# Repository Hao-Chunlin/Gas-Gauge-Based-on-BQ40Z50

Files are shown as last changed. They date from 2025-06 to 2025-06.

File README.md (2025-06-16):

# 基于BQ40Z50电池电量计(Gas Gauge Based on BQ40Z50)
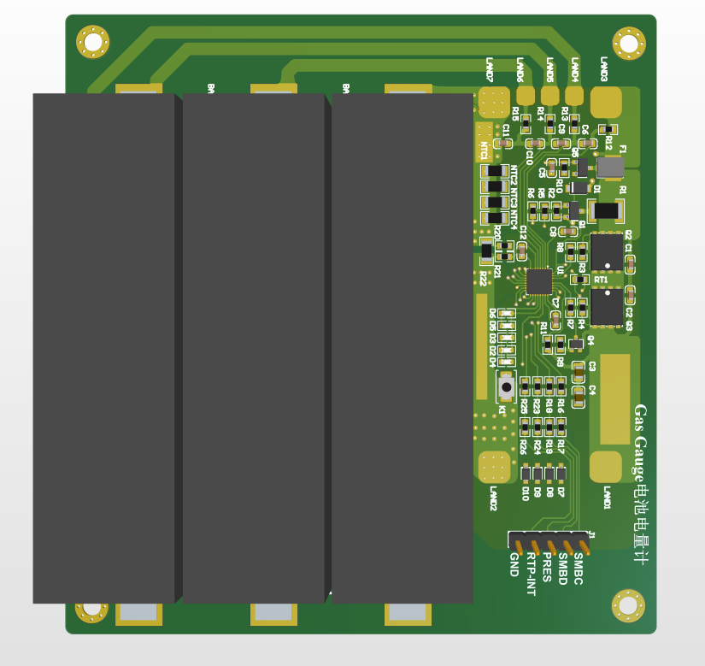
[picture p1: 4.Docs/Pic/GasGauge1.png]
实物图


## 0. 关于本项目
关键解决移动设备电池电量测量不准确问题,本项目采用BQ40Z50RSMR-R1实现对电池运行状态监测及充放电控制;BQ40Z50RSMR-R1内部集成阻抗跟踪算法,该算法是基于锂电池电化学特性来动态学习跟踪电池阻抗,并结合负载变化来预测电池电量,兼顾电压法和库仑计数法优点的同时,支持预充电功能,可对电池进行充分激活;电池状态参数可以通过BQ40Z50RSMR-R1提供的SMBusv1.1系统管理总线接口获取,该接口兼容传统IIC通信协议,仅利用时钟线和数据线便可实现主从设备之间的信息互传.

## 1. 硬件设计
本项目在原理图部分给出了BQ40Z50RSMR-R1完整功能电路,包括供电和电压采样电路,电流采样电路,温度采样电路,一级保护电路,二级保护电路,接口交互电路,如下图所示.但实际上考虑本项目服务于本人某一特定负载应用场景,实际焊接和配置时对其进行了裁剪,取消了"二级保护电路"以及预充电功能.

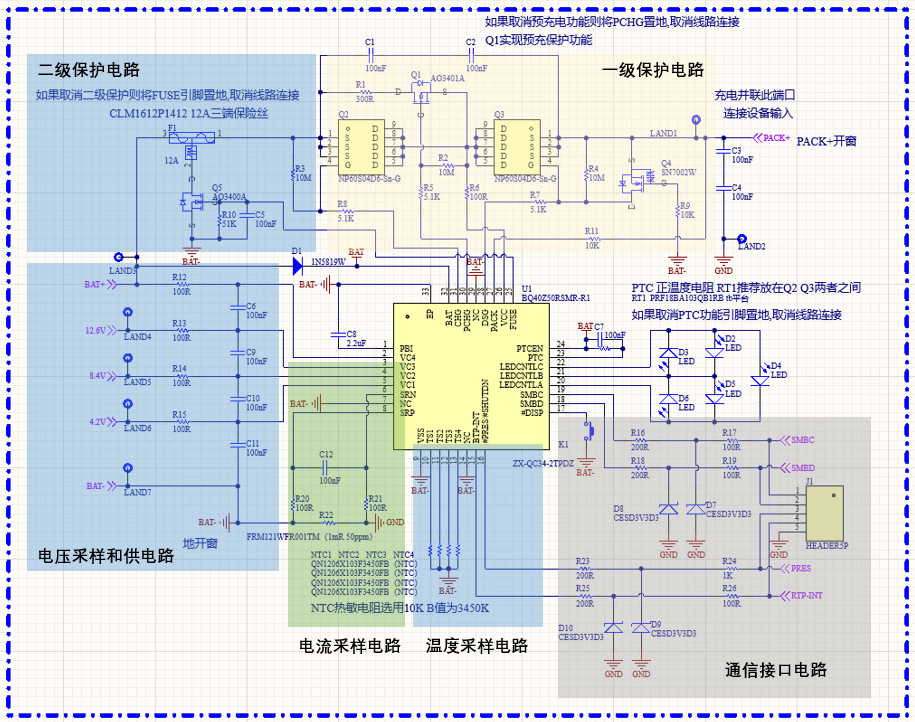
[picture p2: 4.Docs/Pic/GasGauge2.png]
原理图


## 2. 锂电池连接
连接电池时从低压侧逐级向上连接,最大支持4节串级,未使用的接口直接与高压端相短接即可.
本项目测试使用的是三节18650锂电池串级,锂电池型号参数如下:
|参数| | |
|---| --- | --- |
|标准电压值|3.7V| 
|满电电压值|4.2V|
|电池容量值|2550mAh| 

## 3. 固件配置
需要安装Ti官网提供的BQStudio软件对电量计进行配置(其中需要EV2400进行通信),整体配置构成可分为五步:
(具体的详细步骤参考pdf文件)
EV2400如下所示:
EV2400图
>Ti的BQStudio软件运行容易出现卡顿,进行重启即可(EV2400对Win10系统支持)
- 首先进行固件更新下载,更新版本为R2,固件后缀为srec,在Firmware文件中
- 结合硬件设计电路对BQ40Z50RSMR-R1进行具体参数配置,涉及电路保护,充电设置,外接电池参数等
- 对BQ40Z50RSMR-R1进行校准,涉及电流、电压、温度校准,校准电流推荐1-2A,本项目使用6Ω 50W功率电阻作为负载进行电流校准,如下图所示:
 
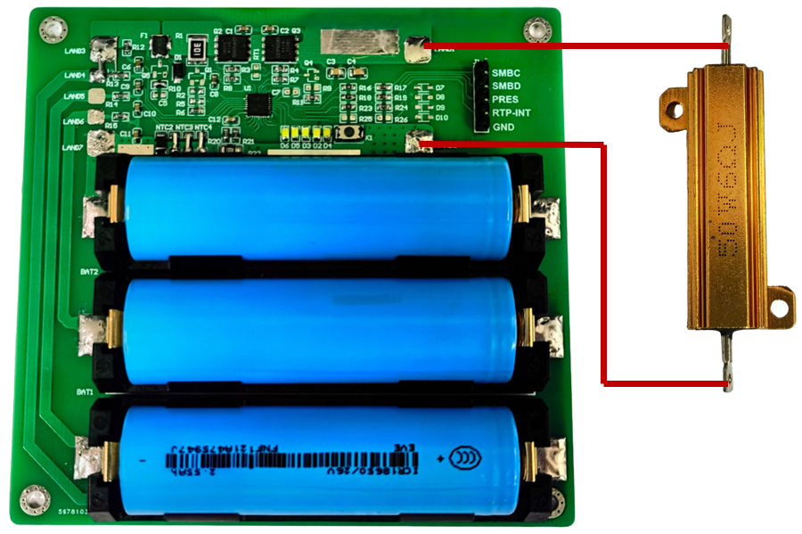
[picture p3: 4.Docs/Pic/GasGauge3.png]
测试图

- Program Selected Chemistry将数据写入芯片(电池化学特性加载)
- 进行多轮完整充放电,对内部阻抗跟踪算法进行训练

## 4. SMBus通信协议构建(软件设计)
电池状态参数可以通过BQ40Z50RSMR-R1提供的SMBusv1.1 系统管理总线接口获取,该接口兼容传统IIC通信协议,仅利用时钟线和数据线便可实现主从设备之间的信息互传.其中需要进行CRC校验,通信协议在Software文件内部,考虑多平台的兼容性,本项目采用模拟IIC,测试平台选用STM32标库.
```
// CRC校验函数
uint8_t calculate_crc8(uint8_t* message, uint8_t len)  // CRC-8校验 X8+X2+X+1
{
  uint8_t crc = 0;
  while (len--) {
    crc ^= (*message++);
    for (uint8_t i = 0; i < 8; i++) {
      if (crc & 0x80)
        crc = (crc << 1) ^ 0x07;
      else
        crc <<= 1;
    }
  }
  return crc;
}
```
电量计通信实例:

```
#include "bq4050.h"
int main(void) {
  delay_init();
  uart_init(115200);
  BQ4050_GPIO_Init();
  for (;;) {
    printf("==================================================\r\n");
    BQ4050_Read_Info();
    printf("电池电压(V)：%.2f\r\n", (float)bq4050.voltage / 1000.0);
    printf("电池电量(%)：%d\r\n", bq4050.relative_SOC);
    printf("电池温度(.C)：%.2f\r\n", bq4050.temperature);
    printf("电池电流(A)： %d\r\n", bq4050.current);
    printf("==================================================\r\n");
    delay_ms(1000);
  }
}
```
## 5. 问题汇总
- 如果在使用EV2400连接芯片时无法识别到,可以考虑将芯片BAT+引脚与PACK+引脚相短接

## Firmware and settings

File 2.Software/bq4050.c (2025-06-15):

#include <stm32f10x_gpio.h>
#include <stm32f10x_rcc.h>
#include "bq4050.h"
#include "delay.h"
#include "string.h"
#include "sys.h"

struct bq4050_type bq4050 = {0};

void BQ4050_GPIO_Init(void) {
  GPIO_InitTypeDef GPIO_InitStructure;
  RCC_APB2PeriphClockCmd(RCC_APB2Periph_GPIOA, ENABLE);

  GPIO_InitStructure.GPIO_Pin = I2C_SCL_Pin;
  GPIO_InitStructure.GPIO_Mode = GPIO_Mode_Out_PP;
  GPIO_InitStructure.GPIO_Speed = GPIO_Speed_50MHz;

  GPIO_Init(GPIOA, &GPIO_InitStructure);
  GPIO_SetBits(GPIOA, I2C_SCL_Pin);

  GPIO_InitStructure.GPIO_Pin = I2C_SDA_Pin;
  GPIO_Init(GPIOA, &GPIO_InitStructure);
  GPIO_SetBits(GPIOA, I2C_SDA_Pin);

  GPIO_SetBits(I2C_SCL_GPIO_Port, I2C_SCL_Pin);
  GPIO_SetBits(I2C_SDA_GPIO_Port, I2C_SDA_Pin);
}

void SDA_OUT(void) {
  GPIO_InitTypeDef GPIO_InitStructure;
  GPIO_InitStructure.GPIO_Pin = I2C_SDA_Pin;
  GPIO_InitStructure.GPIO_Mode = GPIO_Mode_Out_PP;
  GPIO_InitStructure.GPIO_Speed = GPIO_Speed_50MHz;
  GPIO_Init(I2C_SDA_GPIO_Port, &GPIO_InitStructure);
}

void SDA_IN(void) {
  GPIO_InitTypeDef GPIO_InitStructure;
  GPIO_InitStructure.GPIO_Pin = I2C_SDA_Pin;
  GPIO_InitStructure.GPIO_Mode = GPIO_Mode_IPU;
  GPIO_InitStructure.GPIO_Speed = GPIO_Speed_50MHz;
  GPIO_Init(I2C_SDA_GPIO_Port, &GPIO_InitStructure);
}
////////////////////////////////////////////////////////////////////////////////////
// 产生IIC起始信号
void SMBus_Start() {
  delay_us(50);
  SDA_OUT();
  SCL_H;
  SDA_H;
  delay_us(10);
  SDA_L;
  delay_us(10);
  SCL_L;
  delay_us(5);
}

// 产生IIC停止信号
void SMBus_Stop() {
  delay_us(50);
  SDA_OUT();
  SCL_H;
  SDA_L;
  delay_us(10);
  SDA_H;
  delay_us(10);
}

// 产生ACK应答
void SMBus_Ack() {
  SDA_OUT();
  SCL_L;
  SDA_L;
  delay_us(10);
  SCL_H;
  delay_us(10);
  SCL_L;
  delay_us(5);
}

// 不产生ACK应答
void SMBus_NAck() {
  SDA_OUT();
  SCL_L;
  SDA_H;
  delay_us(10);
  SCL_H;
  delay_us(10);
  SCL_L;
  delay_us(5);
}

// 等待应答信号到来,返回值:1表示Ack,0表示NAck
uint8_t SMBus_Wait_Ack() {
  uint16_t timeout = 2000;
  SDA_OUT();
  SCL_L;
  SDA_H;
  SDA_IN();  // SDA设置为输入
  delay_us(50);
  while (READ_SDA) {
    timeout--;
    if (timeout == 0) {
      SMBus_Stop();
      return 1;
    }
    delay_us(1);
  }
  SCL_H;  // 在从机应答期间,给予一个SCL高电平信号
  delay_us(10);
  SCL_L;
  delay_us(10);
  return 0;
}

// 往总线写一个字节内容
void SMBus_Write(uint8_t dat) {
  SDA_OUT();
  for (uint8_t i = 0; i < 8; i++) {
    if ((dat & 0x80) >> 7)
      SDA_H;
    else
      SDA_L;
    dat <<= 1;
    delay_us(10);
    SCL_H;  // 置时钟线为高,通知被控器开始接收数据位
    delay_us(10);
    SCL_L;
    delay_us(10);
  }
  delay_us(5);
}

// 读1个字节,ack=1时,发送ACK,ack=0,发送nACK
uint8_t SMBus_Read() {
  uint8_t receive = 0;
  SDA_IN();  // SDA设置为输入
  SCL_L;
  delay_us(300);  // 读取前要加足够长的延时,不然容易出错
  for (uint8_t i = 0; i < 8; i++) {
    delay_us(20);
    SCL_H;
    receive <<= 1;
    if (READ_SDA)
      receive++;
    delay_us(10);
    SCL_L;
  }
  delay_us(5);
  return receive;
}
////////////////////////////////////////////////////////////////////////////////////
// CRC校验函数
uint8_t calculate_crc8(uint8_t* message, uint8_t len)  // CRC-8校验 X8+X2+X+1
{
  uint8_t crc = 0;
  while (len--) {
    crc ^= (*message++);
    for (uint8_t i = 0; i < 8; i++) {
      if (crc & 0x80)
        crc = (crc << 1) ^ 0x07;
      else
        crc <<= 1;
    }
  }
  return crc;
}

/***
 * @brief SMBus写区块指令,返回0表示正常
 * @param slave_add表示从机地址,放前7位,最后1位无效
 * @param cmd表示写入的寄存器地址
 * @param dat表示要写入的数据的指针
 * @param dat_len表示写入数据的长度
 */
uint8_t SMBus_Write_Block(uint8_t slave_add,
                          uint8_t cmd,
                          uint8_t* dat,
                          uint8_t dat_len) {
  if (dat_len > 64)
    return 0;
  slave_add &= 0xFE;  // 只保留前7位地址
  SMBus_Start();
  SMBus_Write(slave_add);
  if (SMBus_Wait_Ack())
    return 1;

  SMBus_Write(cmd);
  if (SMBus_Wait_Ack())
    return 2;

  SMBus_Write(dat_len);
  if (SMBus_Wait_Ack())
    return 3;

  // 第4位开始为block数据
  for (uint8_t i = 0; i < dat_len; i++) {
    SMBus_Write(dat[i]);
    if (SMBus_Wait_Ack())
      return 4;
  }

  SMBus_Stop();
  return 0;
}

/***
 * @brief SMBus读区块指令,返回实际block数据长度,返回0表示正常
 * @param slave_add表示从机地址,放前7位,最后1位无效
 * @param cmd表示写入的寄存器地址
 * @param dat表示返回的数据要保存到的变量的指针
 * @param dat_len表示读取长度(最多64字节)
 */
uint8_t SMBus_Read_Block(uint8_t slave_add,
                         uint8_t cmd,
                         uint8_t* dat,
                         uint8_t dat_len) {
  if (dat_len > 64)
    return 0;
  slave_add &= 0xFE;  // 只保留前7位地址
  // 保存传输期间所有数据,其格式如下:
  // 从机写地址+命令+从机读地址+后续数据长度+写block时写入的地址(2字节)+数据(最多64字节)
  uint8_t message[70] = {0};
  uint8_t pec = 0;  // 校验字节
  message[0] = slave_add;
  message[1] = cmd;
  message[2] = slave_add + 1;
  SMBus_Start();
  SMBus_Write(slave_add);
  if (SMBus_Wait_Ack())
    return 1;

  SMBus_Write(cmd);
  if (SMBus_Wait_Ack())
    return 2;

  SMBus_Start();
  SMBus_Write(slave_add + 1);
  if (SMBus_Wait_Ack())
    return 3;

  // 读取到的第1个字节为之后接收的数据长度
  message[3] = SMBus_Read();
  if (message[3] != dat_len + 2)
    return 4;
  SMBus_Ack();

  message[4] = SMBus_Read();  // 写block时候发送的寄存器低位地址
  SMBus_Ack();
  message[5] = SMBus_Read();  // 写block时候发送的寄存器高位地址
  SMBus_Ack();

  // 从block中读取数据,最长64个字节
  for (uint8_t i = 0; i < dat_len && i < 64; i++) {
    message[i + 6] = SMBus_Read();
    SMBus_Ack();
  }
  pec = SMBus_Read();
  SMBus_NAck();
  SMBus_Stop();

  if (pec != calculate_crc8(message, dat_len + 6))
    return 5;

  for (uint8_t i = 0; i < dat_len && i < 64; i++)
    dat[i] = message[i + 6];

  return 0;
}

/***
 * @brief SMBus读一个字,返回0表示正常
 * @param slave_add表示从机地址,放前7位,最后1位无效
 * @param cmd表示读取的寄存器地址
 * @param dat表示返回的数据要保存到的变量的指针
 */
uint8_t SMBus_Read_Word(uint8_t slave_add, uint8_t cmd, uint16_t* dat) {
  slave_add &= 0xFE;  // 只保留前7位地址
  // 保存传输期间所有数据,其格式如下:
  // 从机写地址+命令+从机读地址+数据(2字节)
  uint8_t message[5] = {0};
  uint8_t pec = 0;
  message[0] = slave_add;
  message[1] = cmd;
  message[2] = slave_add + 1;
  SMBus_Start();
  SMBus_Write(slave_add);
  if (SMBus_Wait_Ack())
    return 1;

  SMBus_Write(cmd);
  if (SMBus_Wait_Ack())
    return 2;

  SMBus_Start();
  SMBus_Write(slave_add + 1);
  if (SMBus_Wait_Ack())
    return 3;

  message[3] = SMBus_Read();
  SMBus_Ack();
  message[4] = SMBus_Read();
  SMBus_Ack();
  pec = SMBus_Read();  // 数据校验
  SMBus_NAck();
  SMBus_Stop();

  // 对传输数据进行crc校验
  if (pec != calculate_crc8(message, 5))
    return 4;

  *dat = (message[3] | (message[4] << 8));

  return 0;
}

// bq4050通过ManufacturerBlockAccess()读取寄存器数据
uint8_t BQ4050_MAC_Read(uint8_t cmd, uint8_t* dat, uint8_t dat_len) {
  if (dat_len > 64)
    return 1;
  memset(dat, 0, dat_len);
  uint8_t cmd_list[2] = {cmd, 0x00};
  if (SMBus_Write_Block(BQ4050_ADDRRESS, 0x44, cmd_list, 2))
    return 2;
  if (SMBus_Read_Block(BQ4050_ADDRRESS, 0x44, dat, dat_len))
    return 3;
  return 0;
}
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

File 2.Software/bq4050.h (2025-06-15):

#ifndef __BQ4050_H
#define __BQ4050_H

#define I2C_SCL_GPIO_Port GPIOA
#define I2C_SDA_GPIO_Port GPIOA
#define I2C_SCL_Pin GPIO_Pin_0
#define I2C_SDA_Pin GPIO_Pin_1

#define READ_SDA GPIO_ReadInputDataBit(I2C_SDA_GPIO_Port, I2C_SDA_Pin)
#define SCL_H GPIO_WriteBit(I2C_SCL_GPIO_Port, I2C_SCL_Pin, Bit_SET)
#define SCL_L GPIO_WriteBit(I2C_SCL_GPIO_Port, I2C_SCL_Pin, Bit_RESET)
#define SDA_H GPIO_WriteBit(I2C_SDA_GPIO_Port, I2C_SDA_Pin, Bit_SET)
#define SDA_L GPIO_WriteBit(I2C_SDA_GPIO_Port, I2C_SDA_Pin, Bit_RESET)

void BQ4050_GPIO_Init(void);
void SDA_OUT(void);
void SDA_IN(void);

#define BQ4050_ADDRRESS 0x16

struct bq4050_type {
  uint16_t manufacturer_num;
  uint16_t absolute_SOC;
  uint16_t relative_SOC;
  float temperature;
  uint16_t voltage;
  int16_t current;
  int16_t power;
  uint16_t cell_voltage_arr[4];
  int16_t cell_current_arr[4];
  int16_t temperature_arr[7];
};
extern struct bq4050_type bq4050;
uint8_t BQ4050_Read_Info(void);
uint8_t SMBus_Read_Word(uint8_t slave_add, uint8_t cmd, uint16_t* dat);
#endif
